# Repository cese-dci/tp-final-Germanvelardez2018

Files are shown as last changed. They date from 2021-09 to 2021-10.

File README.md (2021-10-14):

## Trabajo práctico final de la asignatura DCI ##
Este repositorio contiene el trabajo práctico final para la asignatura de Diseño de Circuitos Impresos de la carrera de posgrado de FIUBA.

* Autor: German Gabriel Velardez
* Título corto del trabajo:  Replica de modulo de comunicacion basado en el chip SIM7000G
* Descripción:  Modulo de comunicacion basado GSM/4G con GNSS incluido.

## Licencia de este trabajo ##
La licencia utilizada en este proyecto es : <b>CERN Open Hardware Licence Version 2</b>. 

## Estructura del TP FINAL ##

Se repositorio esta estructurado de la siguiente manera.

* doc: Toda la información sobre el circuito, principalmente de autoría o procesamiento propio. 
* info: Toda la iformación recolectada sobre el circuito, como por ejemplo:
  * Hojas de datos.
  * Info de productos comerciales.
  * Info en internet.
* pcb: Archivos de diseño esquemático y pcb.

## Replica de modulo de comunicacion basado en SIM7000
# Diseño final

 ### Dimensiones del nuevo modulo:
  <ul>
    <li>
     Largo: 80 mm
    </li>  
    <li>
    Ancho: 60 mm
    </li> 
  </lu> 

  ### Primera tentativa de posicionamiento de elementos
  
<p align="center">
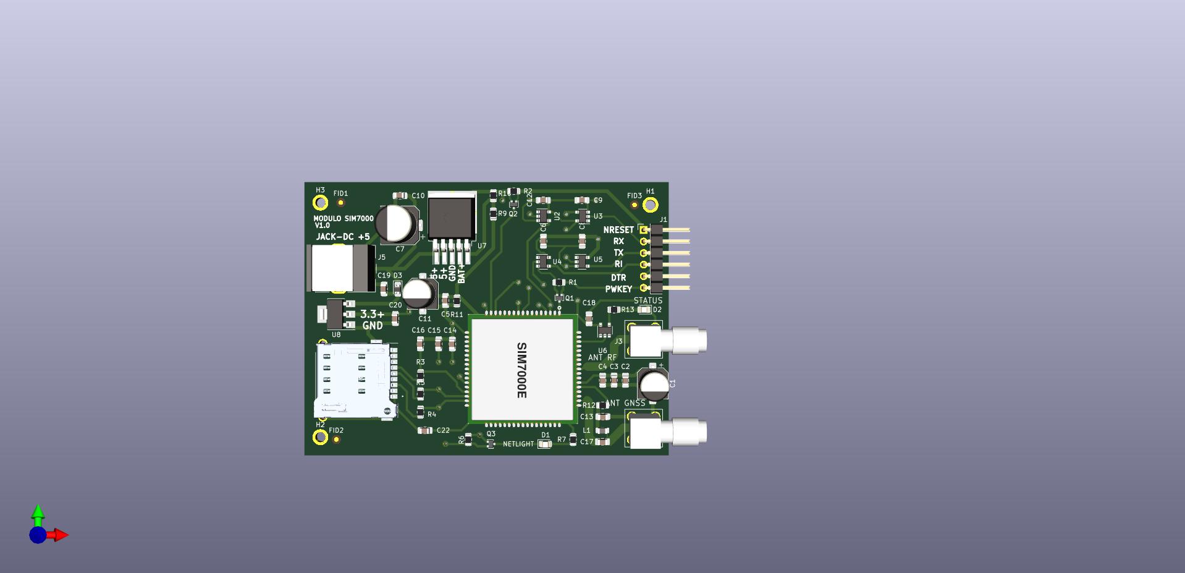
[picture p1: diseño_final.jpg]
  
</p>

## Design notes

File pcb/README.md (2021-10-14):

## Archivos Kicad ##
Este directorio contiene 2 carpetas:
<ul>
  <li>[lib] Librerias de componentes y modelos 3D</li>
  <li>[modulo_SIM7000G] Carpeta del proyecto KICAD</li>
  <ul>

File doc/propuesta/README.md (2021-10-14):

## Propuesta ##
En este directorio debe ir OBLIGATORIAMENTE la información que se presentó al momento de acordar la propuesta de TP con el docente. Es decir:
* Fotos e imágenes de las placas de ambos lados si es una réplica. 
* Fotos e imágenes de los prototipos cableados o pruebas si es un trabajo de tesis.
* Urls o info de origen. 
* Circuito esquemático de referencia (si es una réplica) o borrador si es un trabajo de tesis.
* Resumen de la función u objetivo del circuito si es un trabajo de tesis.
* Cualquier otra nota que se haya usado para definir el TP en el formulario de propuesta.

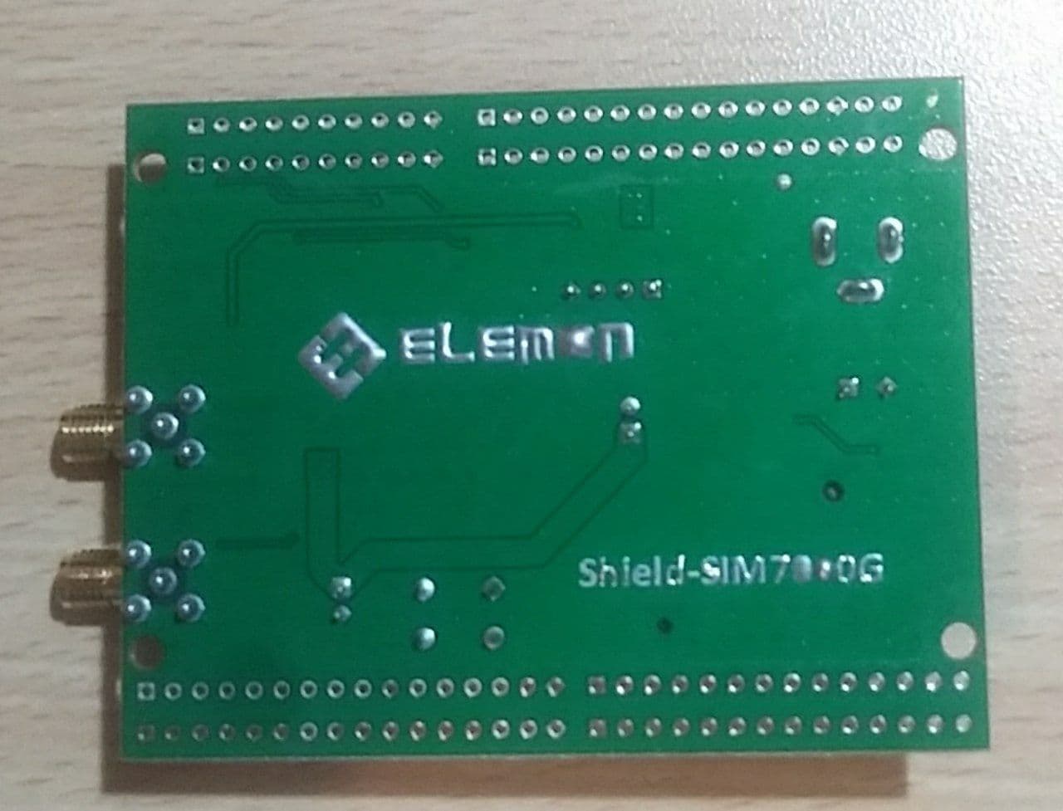
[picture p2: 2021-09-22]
doc/propuesta/fotos/vista_inferior.jpg

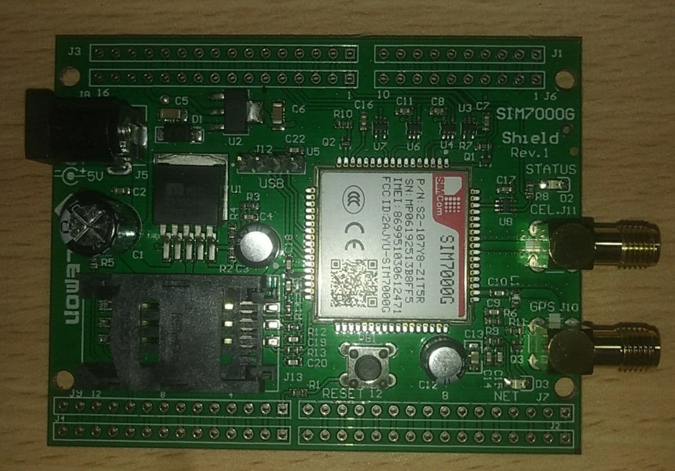
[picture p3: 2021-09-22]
doc/propuesta/fotos/vista_superior_flash.jpg

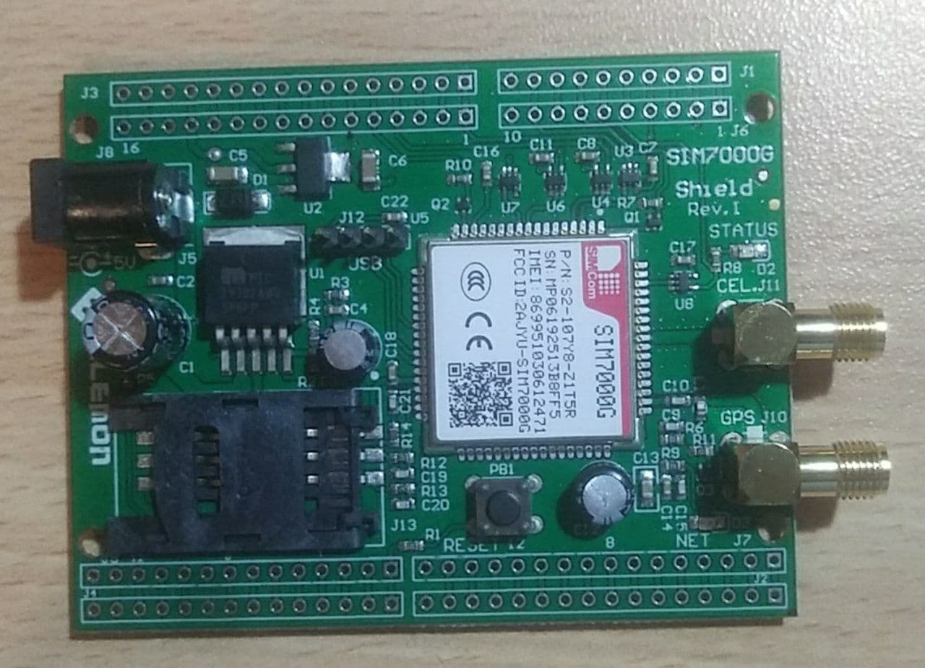
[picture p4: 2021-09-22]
doc/propuesta/fotos/vista_superior.jpg

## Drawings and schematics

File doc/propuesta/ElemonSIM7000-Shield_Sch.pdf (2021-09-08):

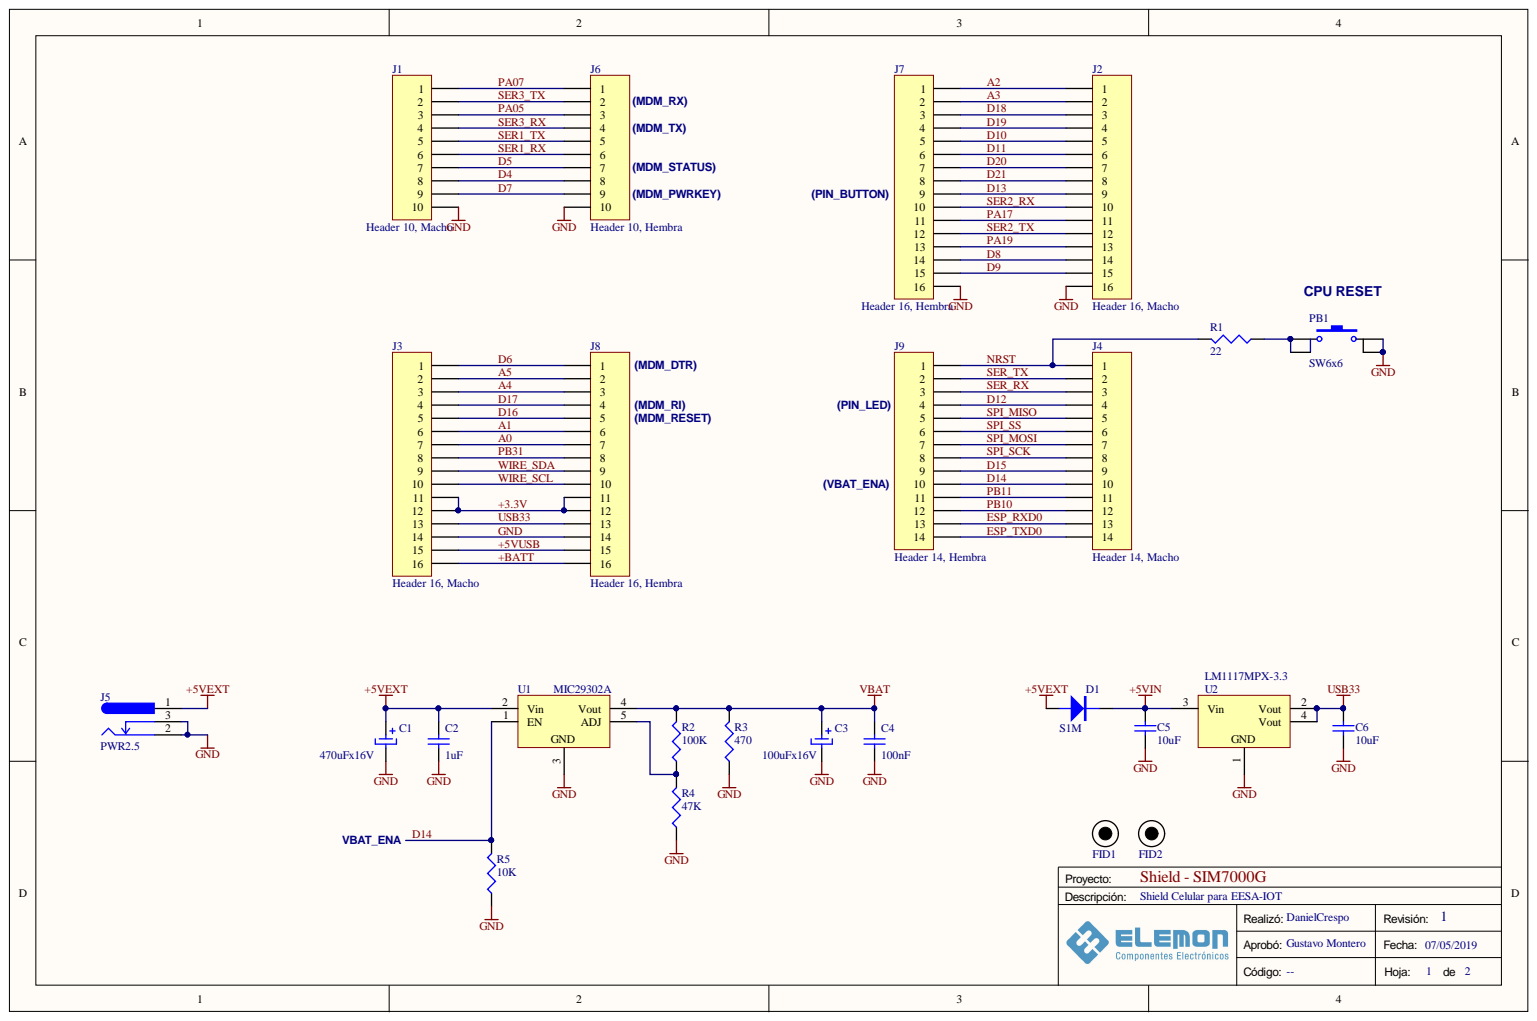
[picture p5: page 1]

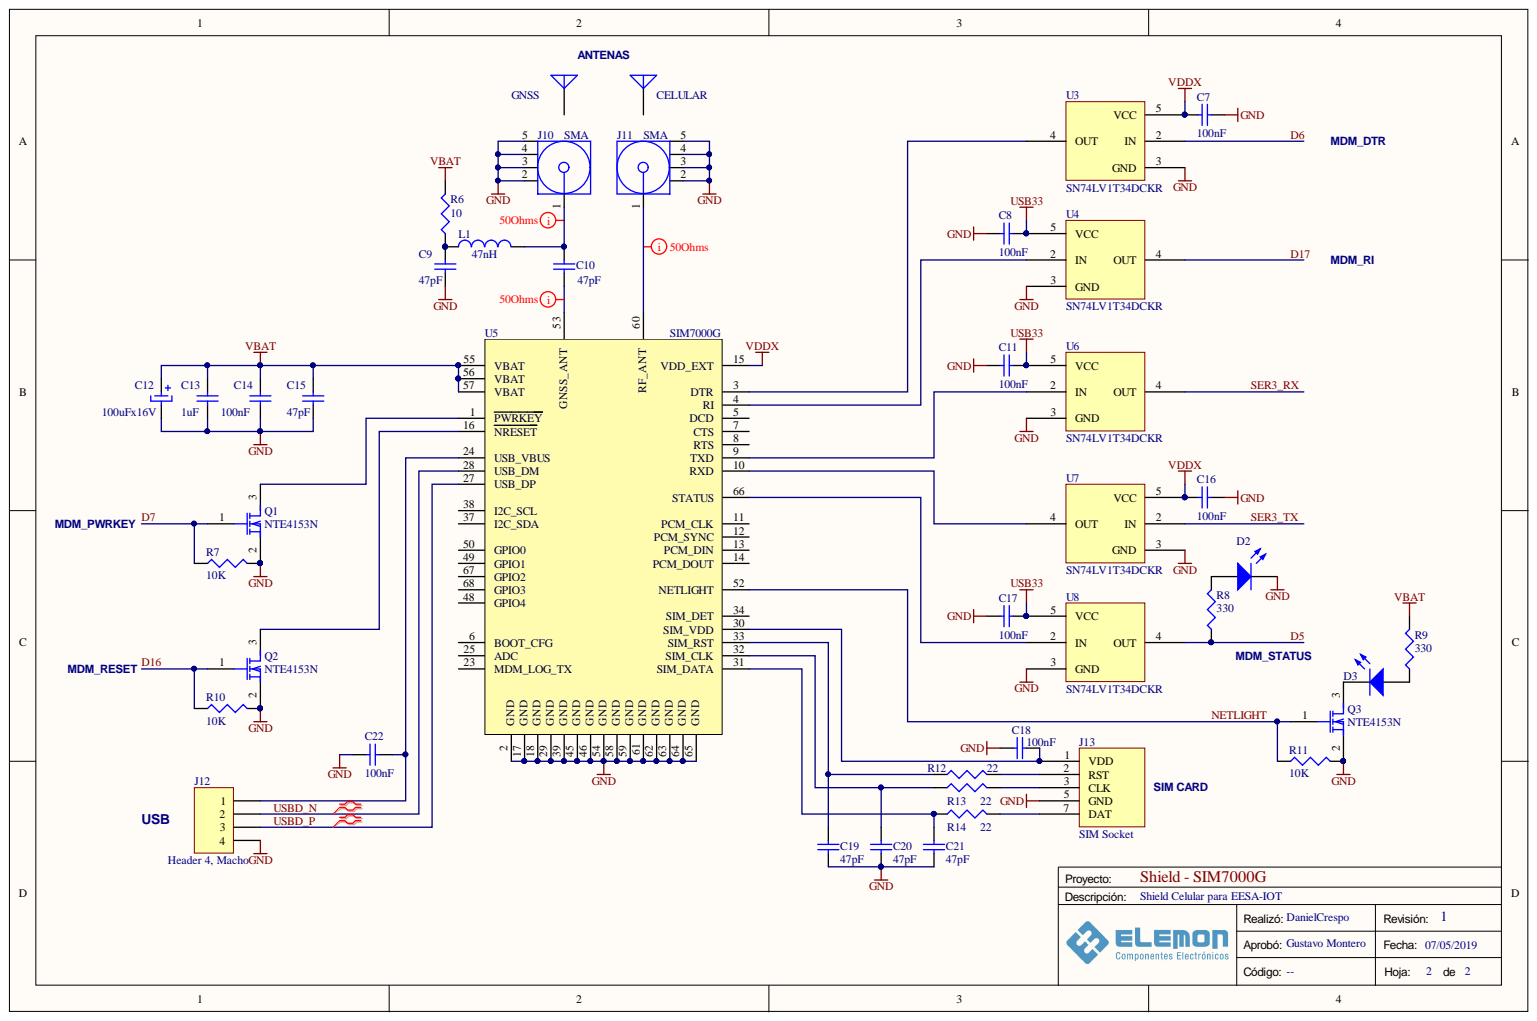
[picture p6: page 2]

2 4
2 8
2 7 | | 6 6

4 9 | 1 4
6 7 | 5 2 | 4 LV1T34DCKR

NTE4 153 N C 2 2 100 n F | | 3 3 | 100 n

2 5 | 3 2 | | FGND | 3

GND 65 GND 64 GND 63 GND 62 GND 61 GND 59 GND 58 GND 54 GND 46 GND 45 GND 39 GND 29 GND 18 GND 17 GND 2 MDM_LOG_TX

US BD_ N
US BD_ P

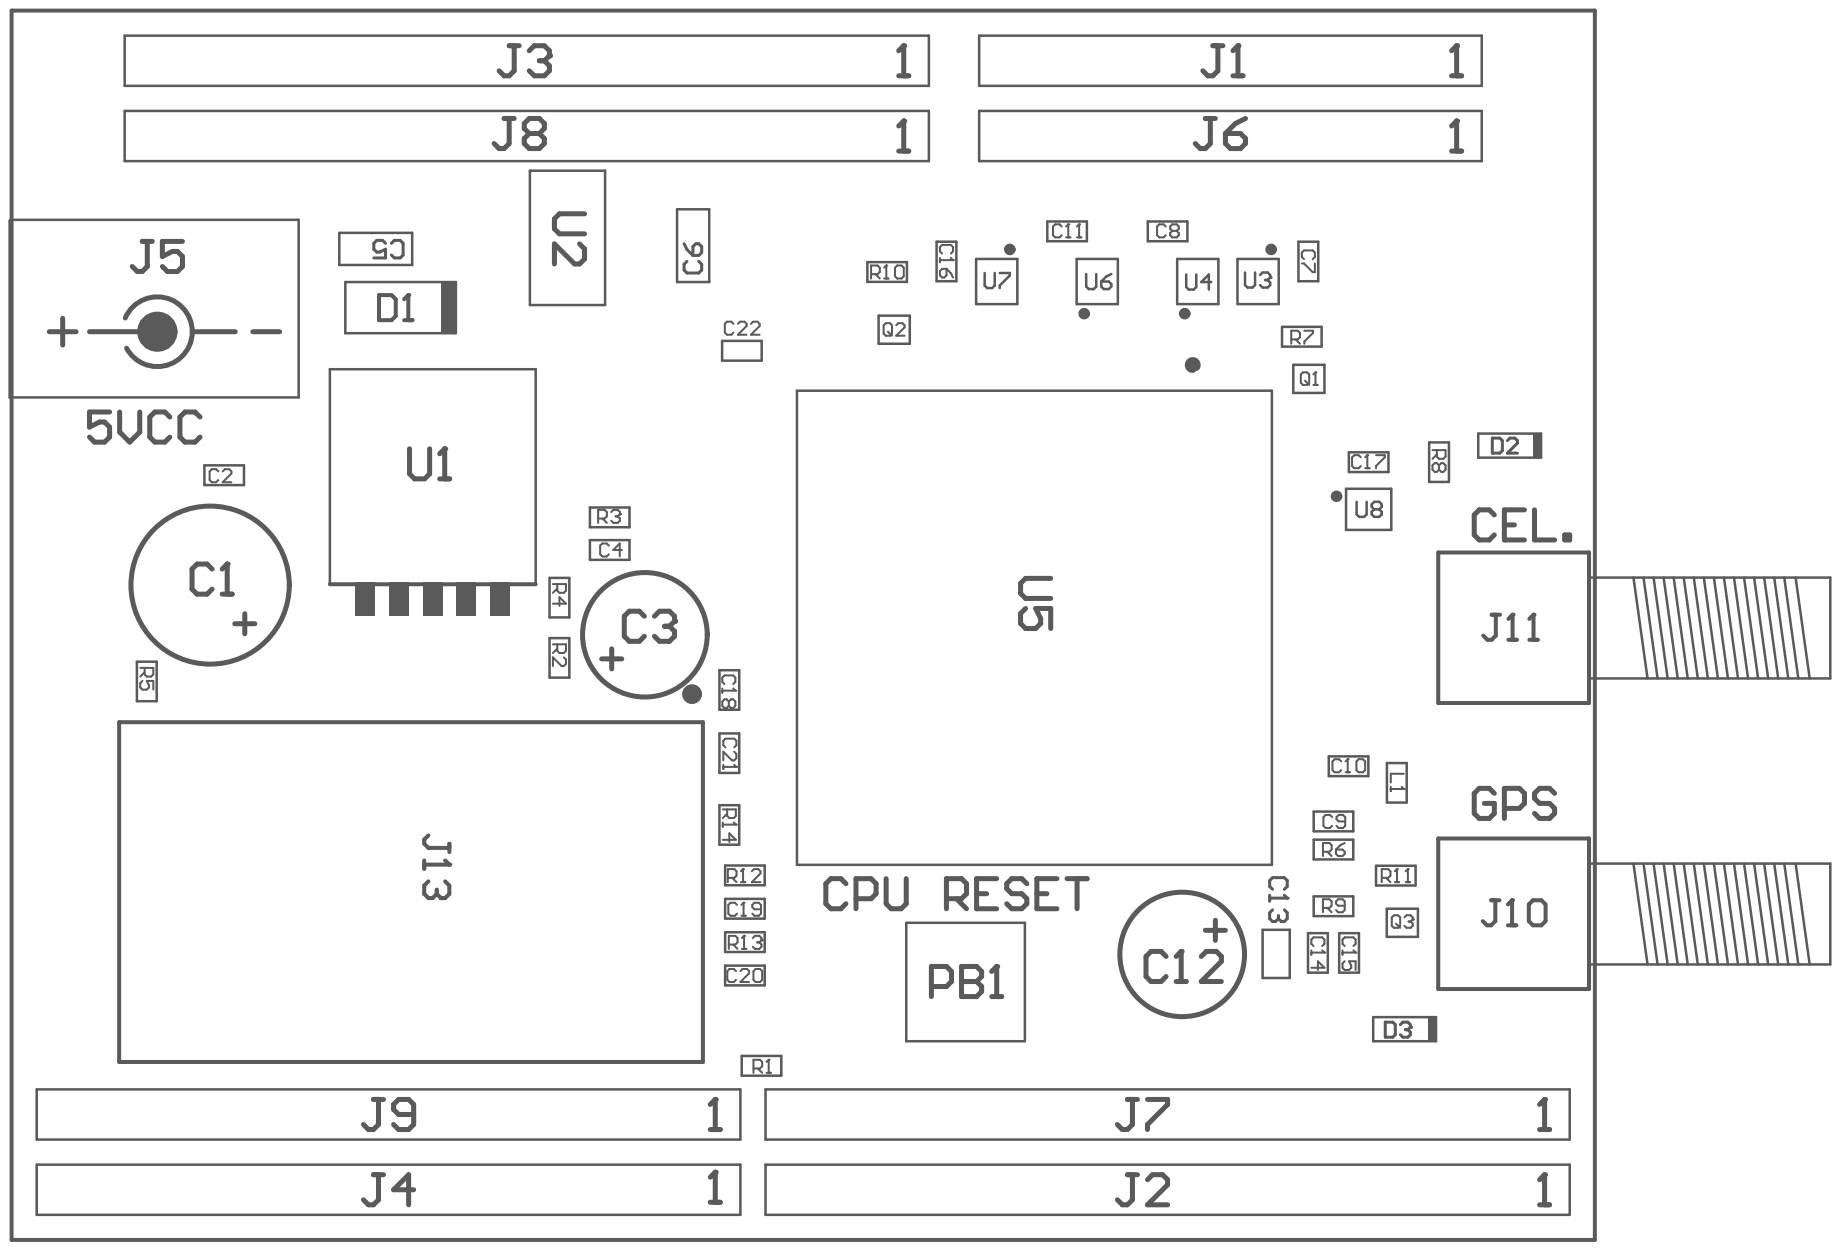
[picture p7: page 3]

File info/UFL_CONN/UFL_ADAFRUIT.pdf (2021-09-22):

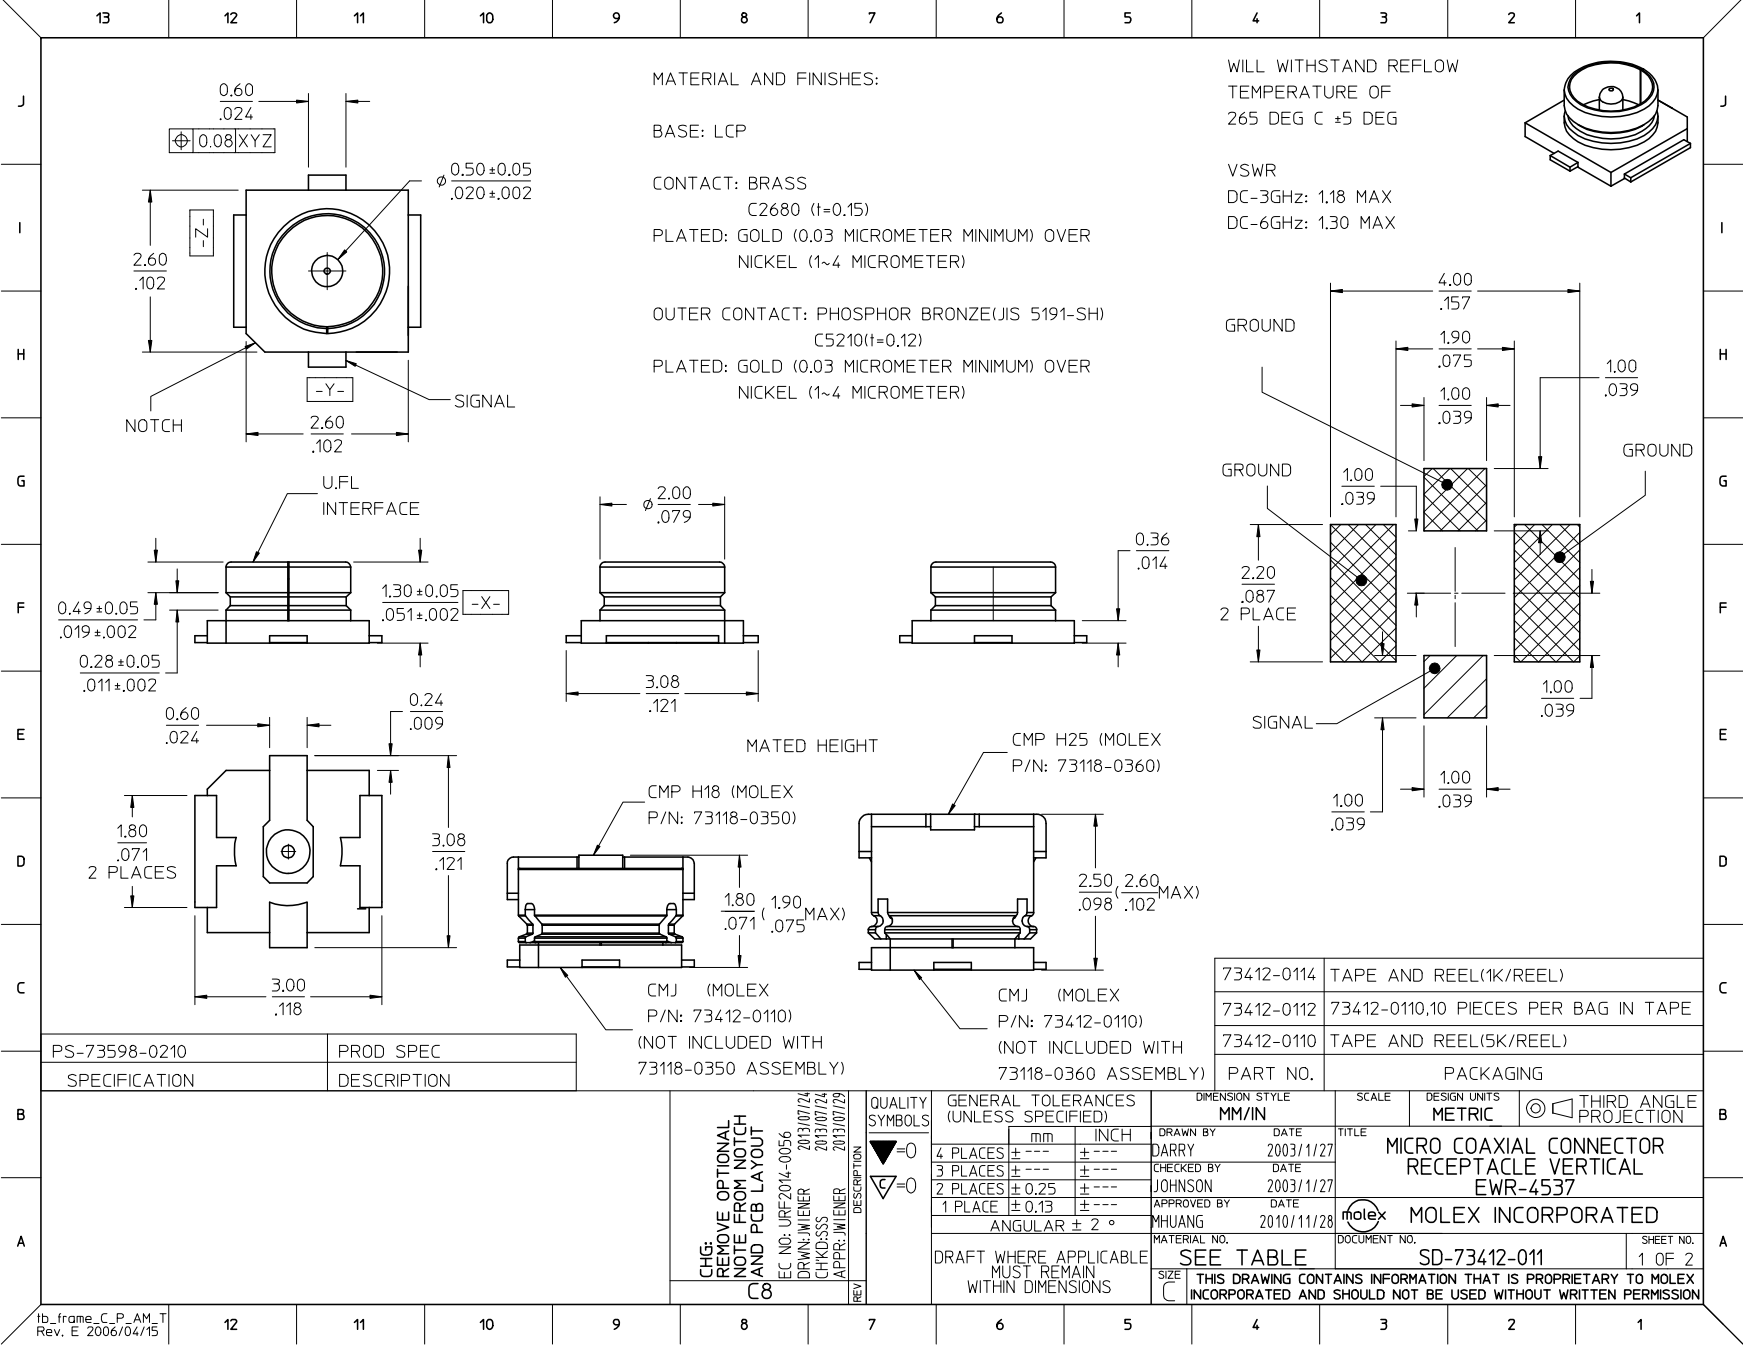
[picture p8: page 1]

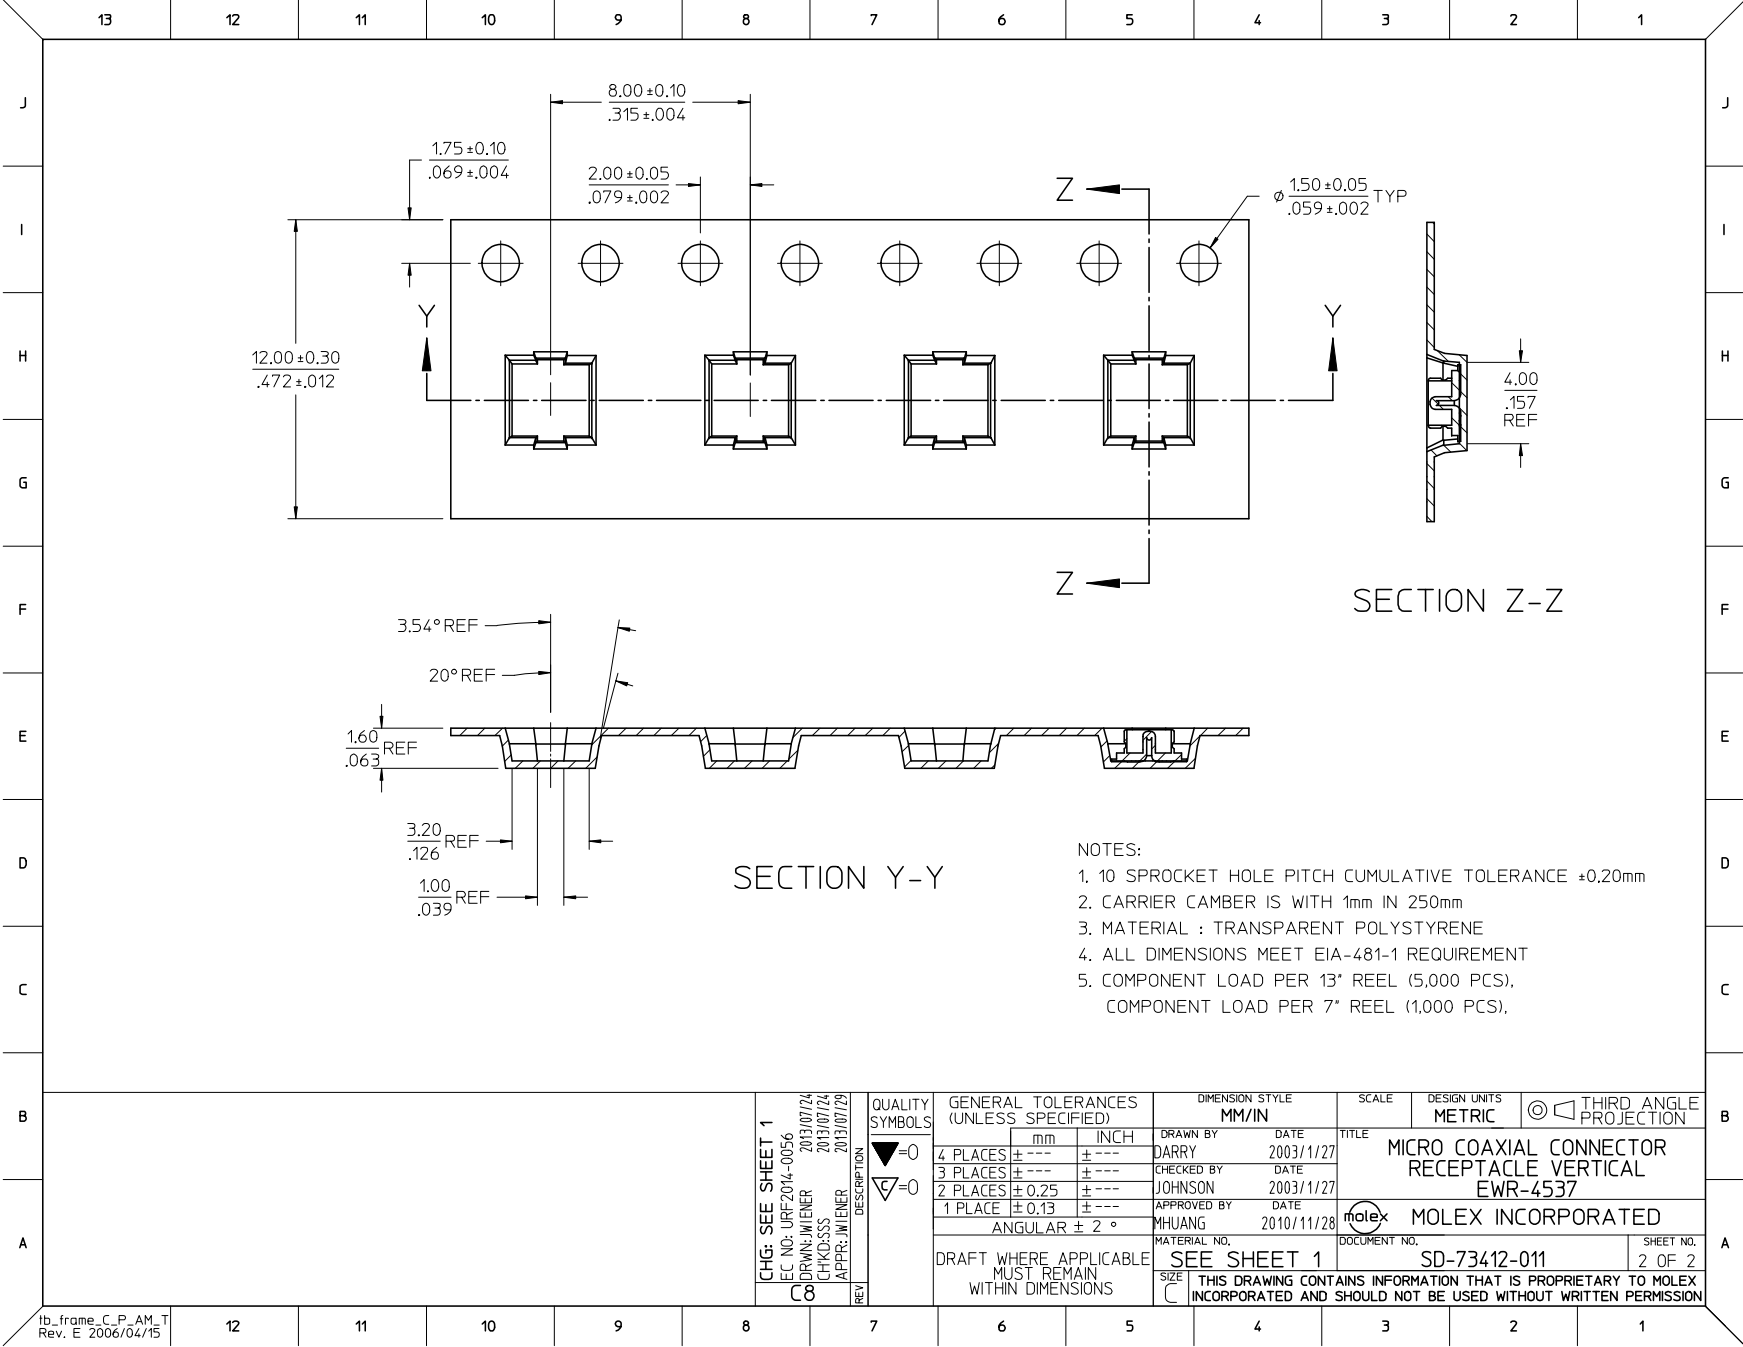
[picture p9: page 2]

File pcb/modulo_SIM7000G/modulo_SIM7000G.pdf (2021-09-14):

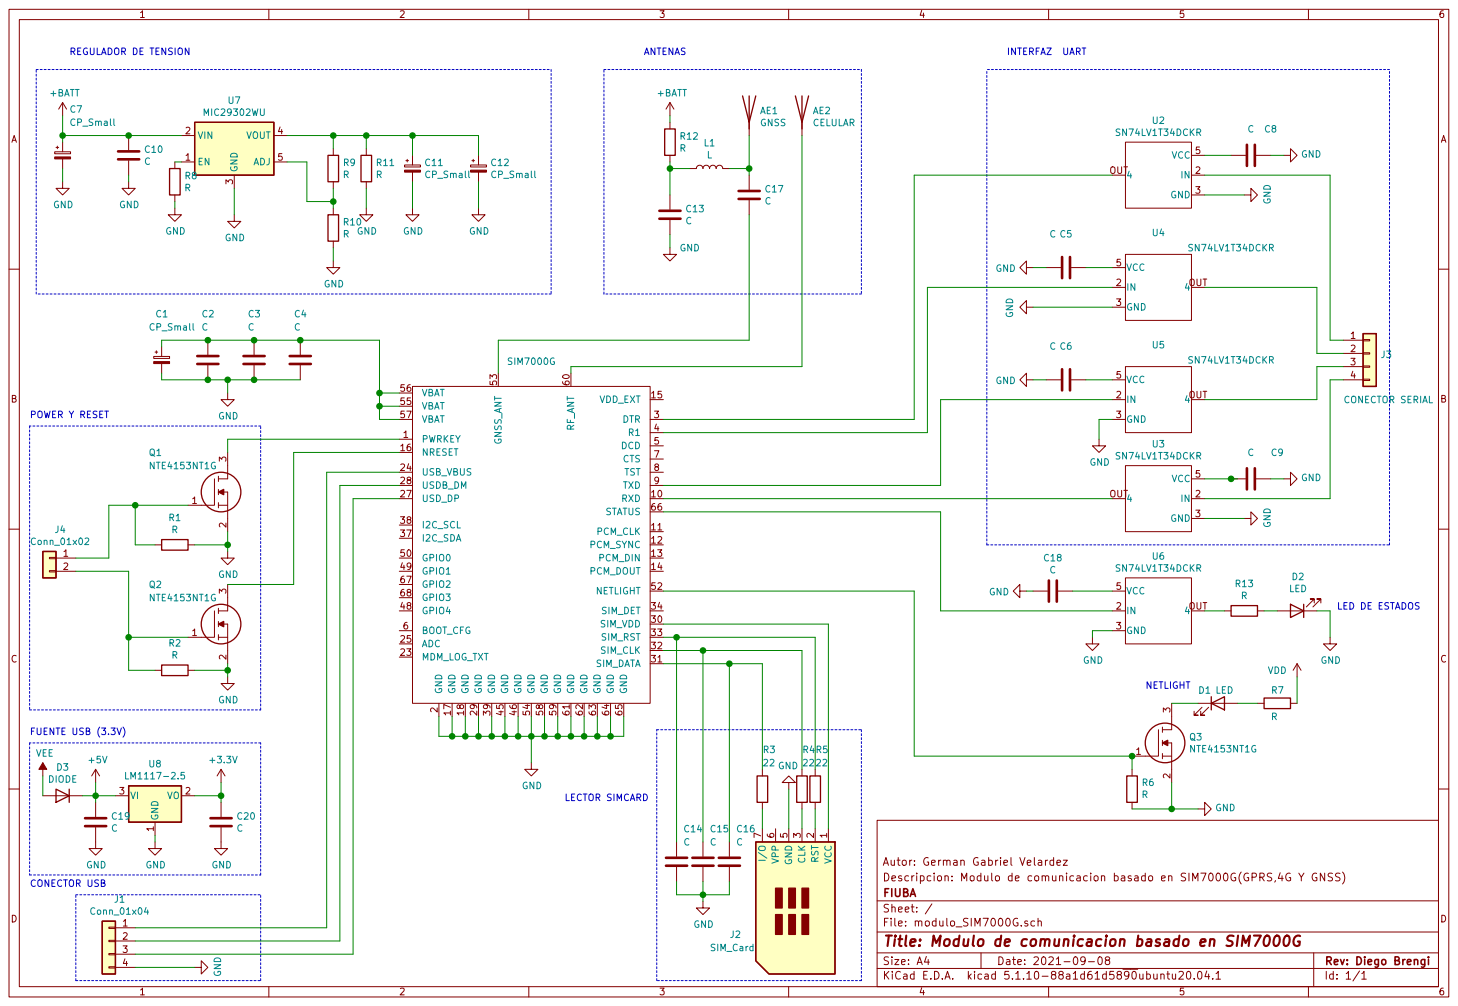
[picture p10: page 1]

Descripcion: Modulo de comunicacion basado en SIM7000G(GPRS,4G Y GNSS) Autor: German Gabriel Velardez

File: modulo_SIM7000G.sch Sheet: / FIUBA

Id: 1/1 Title: Modulo de comunicacion basado en SIM7000G

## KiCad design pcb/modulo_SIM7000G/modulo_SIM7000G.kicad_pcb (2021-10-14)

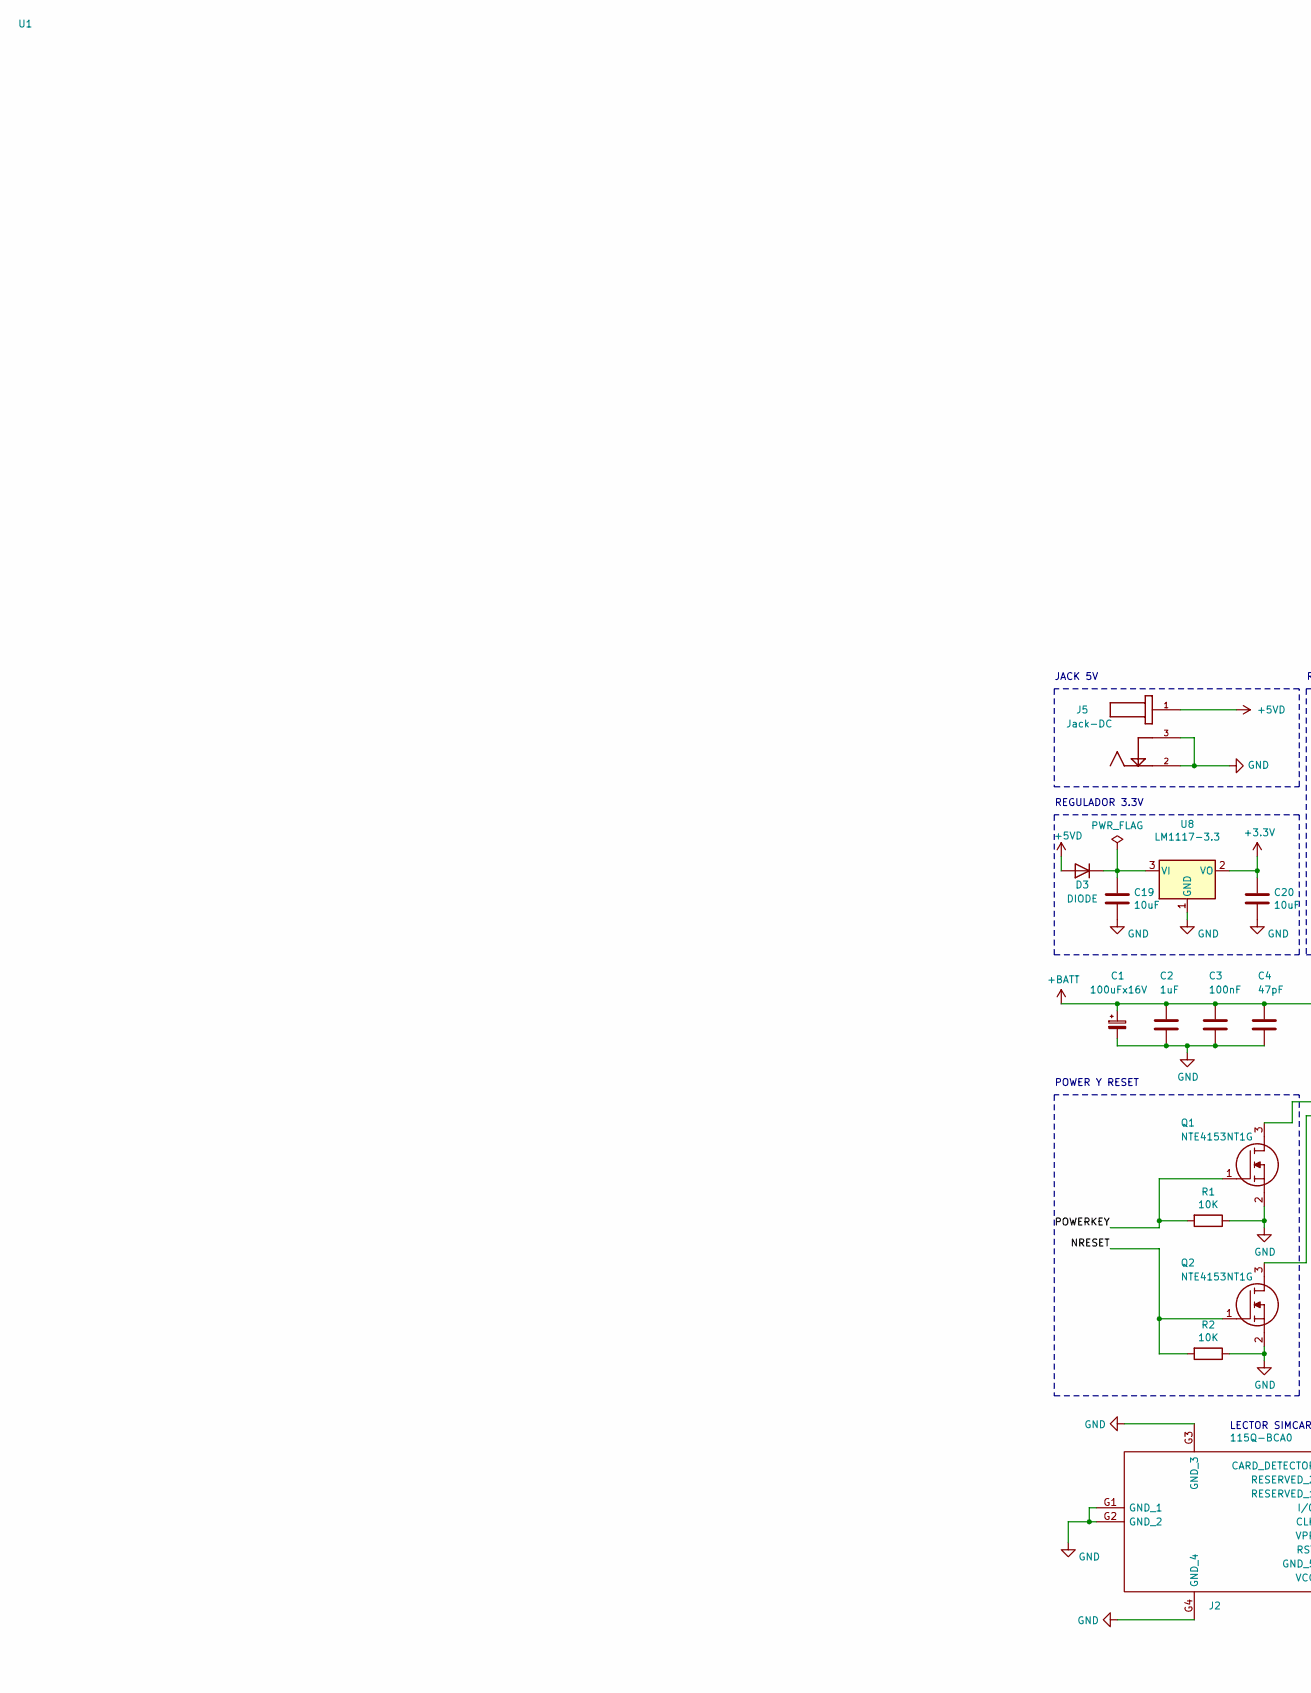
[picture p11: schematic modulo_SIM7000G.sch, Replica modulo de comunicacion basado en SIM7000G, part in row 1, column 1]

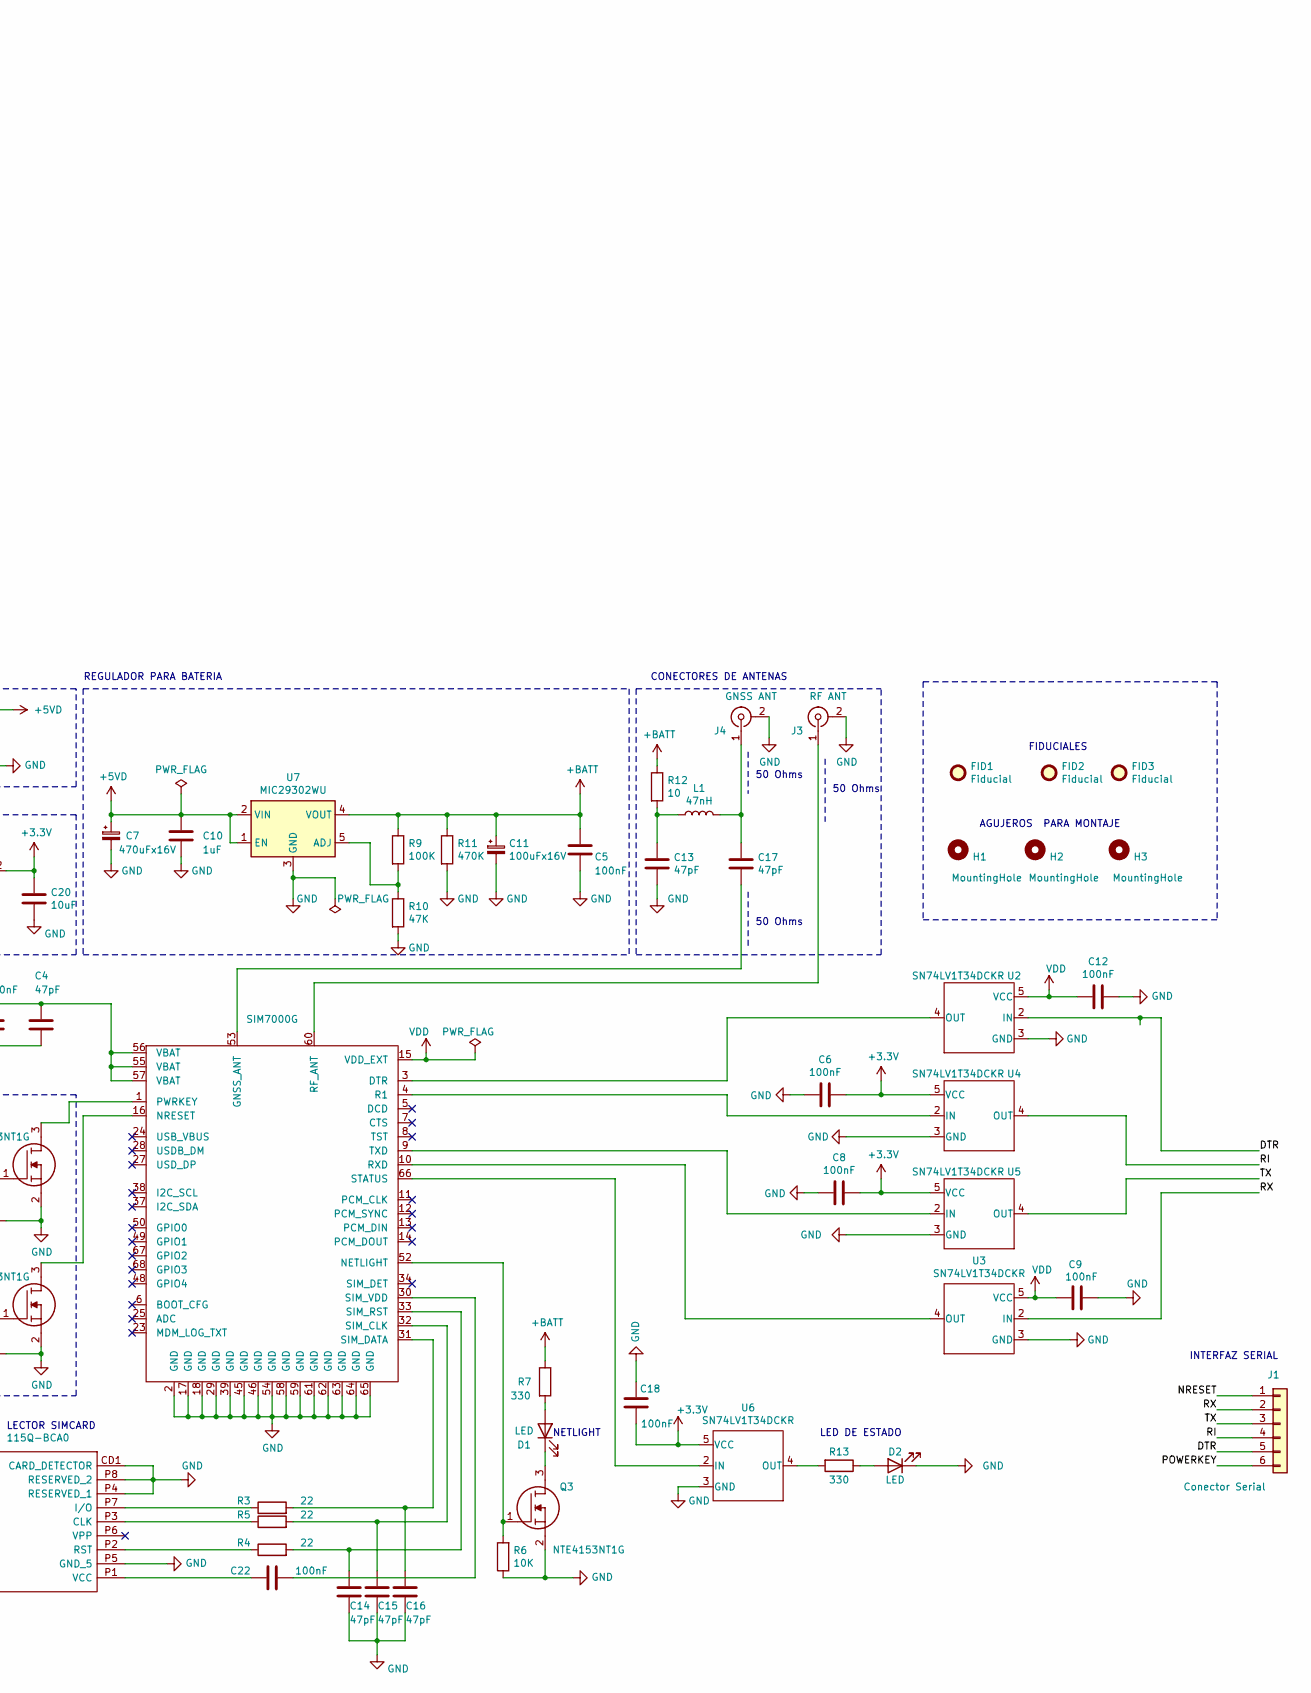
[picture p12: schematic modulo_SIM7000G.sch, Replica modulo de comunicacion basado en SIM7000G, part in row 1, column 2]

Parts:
C1, C11: 100uFx16V; CP_Elec_6.3x9.9
C2, C10: 1uF; C_0805_2012Metric_Pad1.18x1.45mm_HandSolder
C3, C5, C6, C8, C9, C12, C18, C22: 100nF; C_0805_2012Metric_Pad1.18x1.45mm_HandSolder
C4, C13, C14, C15, C16, C17: 47pF; C_0805_2012Metric_Pad1.18x1.45mm_HandSolder
C7: 470uFx16V; CP_Elec_8x10
C19, C20: 10uF; C_0805_2012Metric_Pad1.18x1.45mm_HandSolder
D1, D2: LED; LED_0805_2012Metric
D3: DIODE; D_0805_2012Metric_Pad1.15x1.40mm_HandSolder
FID1, FID2, FID3: Fiducial; Fiducial_1mm_Mask2mm
H1, H2, H3: MountingHole; MountingHole_2.2mm_M2_ISO7380_Pad_TopBottom
J1: Conector Serial; PinHeader_1x06_P2.54mm_Horizontal
J2: 115Q-BCA0; 115QBCA0; Manufacturer_Part_Number 115Q-BCA0
J3: RF ANT; SMA_Amphenol_132203-12_Horizontal
J4: GNSS ANT; SMA_Amphenol_132203-12_Horizontal
J5: Jack-DC; BarrelJack_CUI_PJ-063AH_Horizontal
L1: 47nH; L_0805_2012Metric
Q1, Q2, Q3: NTE4153NT1G; SOT-416; Manufacturer_Part_Number NTE4153NT1G; Mouser Part Number 863-NTE4153NT1G
R1, R2, R6: 10K; R_0805_2012Metric
R3, R4, R5: 22; R_0805_2012Metric
R7, R13: 330; R_0805_2012Metric
R9: 100K; R_0805_2012Metric
R10: 47K; R_0805_2012Metric
R11: 470K; R_0805_2012Metric
R12: 10; R_0805_2012Metric
U1: SIM7000G; SIM7000
U2, U3, U4, U5, U6: SN74LV1T34DCKR; SOT-23-5
U7: MIC29302WU; TO-263-5_TabPin3; Digikey 576-1125-2-NDTR
U8: LM1117-3.3; SOT-223

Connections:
+3V3: C6.2, C8.2, C18.1, C20.1, U4.5 (VCC), U5.5 (VCC), U6.5 (VCC), U8.2 (VO)
+5VD: C7.1, C10.1, D3.1 (A), J5.1, U7.1 (EN), U7.2 (VIN)
+BATT: C1.1, C2.1, C3.1, C4.1, C5.1, C11.1, R7.1, R9.1, R11.1, R12.1, U1.55 (VBAT), U1.56 (VBAT), U1.57 (VBAT), U7.4 (VOUT)
/DTR: J1.5, U2.2 (IN)
/NRESET: J1.1, Q2.1, R2.2
/POWERKEY: J1.6, Q1.1, R1.2
/RI: J1.4, U4.4 (OUT)
/RX: J1.2, U3.2 (IN)
/TX: J1.3, U5.4 (OUT)
GND: C1.2, C2.2, C3.2, C4.2, C5.2, C6.1, C7.2, C8.1, C9.2, C10.2, C11.2, C12.2, C13.2, C14.2, C15.2, C16.2, C18.2, C19.2, C20.2, D2.1 (K), J2.CD1 (CARD_DETECTOR), J2.G1 (GND_1), J2.G2 (GND_2), J2.G3 (GND_3), J2.G4 (GND_4), J2.P4 (RESERVED_1), J2.P5 (GND_5), J2.P8 (RESERVED_2), J3.2 (Ext), J4.2 (Ext), J5.2, J5.3, Q1.2, Q2.2, Q3.2, R1.1, R2.1, R6.1, R10.2, R11.2, U1.2 (GND), U1.17 (GND), U1.18 (GND), U1.29 (GND), U1.39 (GND), U1.45 (GND), U1.46 (GND), U1.54 (GND), U1.58 (GND), U1.59 (GND), U1.61 (GND), U1.62 (GND), U1.63 (GND), U1.64 (GND), U1.65 (GND), U2.3 (GND), U3.3 (GND), U4.3 (GND), U5.3 (GND), U6.3 (GND), U7.3 (GND), U8.1 (GND)
unnamed: C13.1, L1.1, R12.2
unnamed: C14.1, R4.2, U1.33 (SIM_RST)
unnamed: C15.1, R5.2, U1.32 (SIM_CLK)
unnamed: C16.1, R3.2, U1.31 (SIM_DATA)
unnamed: C17.1, J4.1 (In), L1.2
unnamed: C17.2, U1.53 (GNSS_ANT)
unnamed: C19.1, D3.2 (K), U8.3 (VI)
unnamed: C22.1, J2.P1 (VCC)
unnamed: C22.2, U1.30 (SIM_VDD)
unnamed: D1.1 (K), Q3.3
unnamed: D1.2 (A), R7.2
unnamed: D2.2 (A), R13.1
unnamed: J2.P2 (RST), R4.1
unnamed: J2.P3 (CLK), R5.1
unnamed: J2.P7 (I/O), R3.1
unnamed: J3.1 (In), U1.60 (RF_ANT)
unnamed: Q1.3, U1.1 (PWRKEY)
unnamed: Q2.3, U1.16 (NRESET)
unnamed: Q3.1, R6.2, U1.52 (NETLIGHT)
unnamed: R9.2, R10.1, U7.5 (ADJ)
unnamed: R13.2, U6.4 (OUT)
unnamed: U1.3 (DTR), U2.4 (OUT)
unnamed: U1.4 (R1), U4.2 (IN)
unnamed: U1.9 (TXD), U5.2 (IN)
unnamed: U1.10 (RXD), U3.4 (OUT)
unnamed: U1.66 (STATUS), U6.2 (IN)
VDD: C9.1, C12.1, U1.15 (VDD_EXT), U2.5 (VCC), U3.5 (VCC)

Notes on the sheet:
REGULADOR 3.3V
POWER Y RESET
FIDUCIALES
AGUJEROS PARA MONTAJE
JACK 5V
REGULADOR PARA BATERIA
LECTOR SIMCARD
NETLIGHT
LED DE ESTADO
CONECTORES DE ANTENAS
INTERFAZ SERIAL
50 Ohms

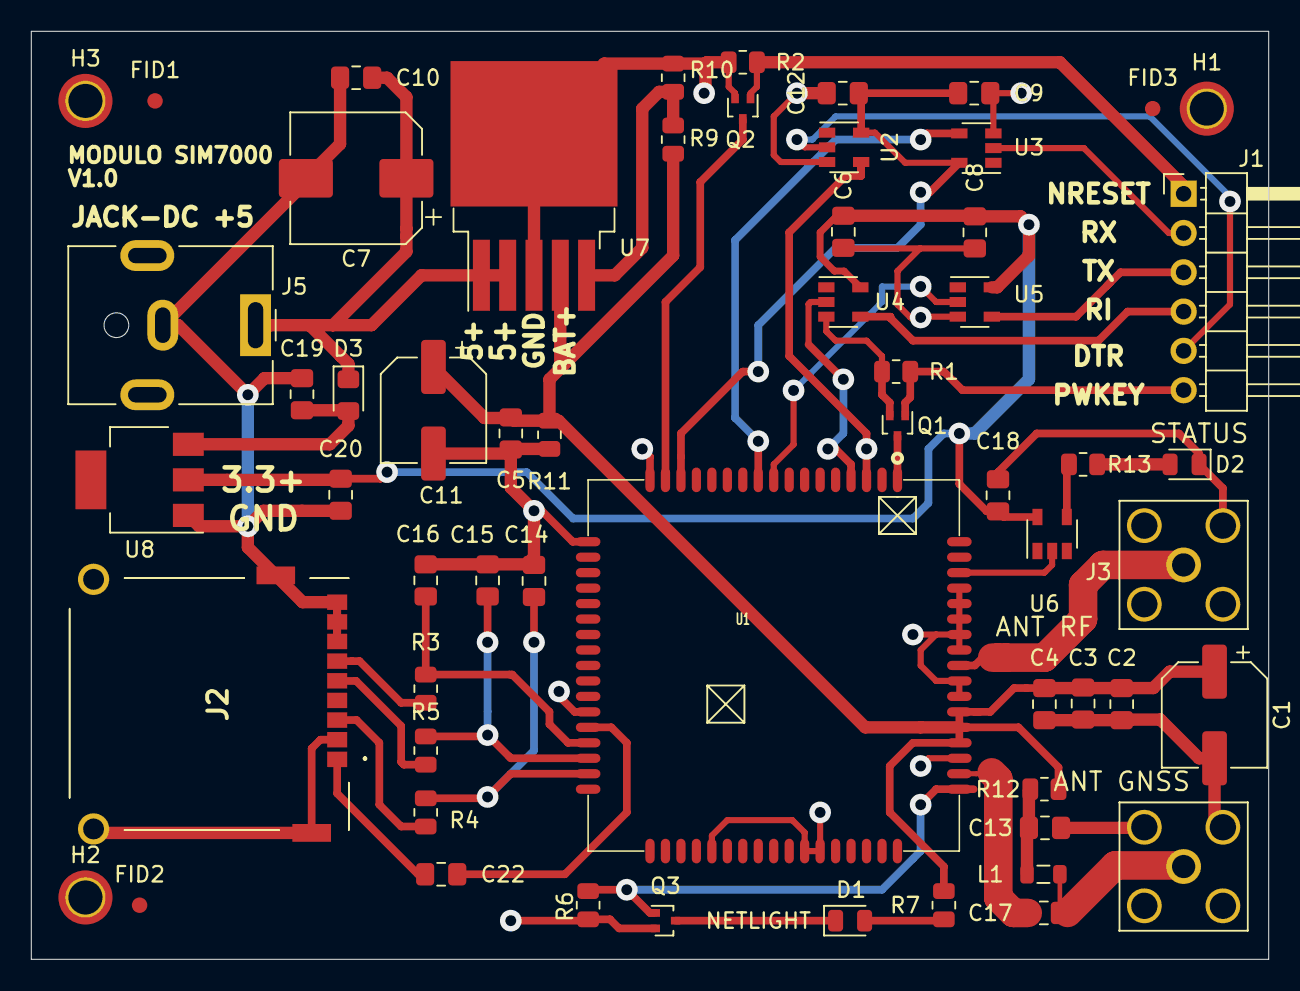
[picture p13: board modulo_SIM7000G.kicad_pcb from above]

Board: 2 copper layers, 80.0 x 60.0 mm, 59 parts (0 on the bottom side), 37 nets.

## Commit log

2021-09-08 Se Completado datos en el readme
2021-09-08 Avances en el esquematico del circuito
    [modulo_SIM7000G.kicad_pcb, modulo_SIM7000G.sch]
2021-09-14 avances en el esquematico(casi terminado) consultar detalles sobre como poner referencias a USB33, VBAT, VEXT, ect
    [modulo_SIM7000G.sch]
2021-09-14 mejora en el esquematico
    [modulo_SIM7000G.sch]
2021-09-14 avance en el esquematico, se posiciono todos los componentes, solo falta agregar VBAT, V5EXT y otras referencia de tension donde corresponda
    [modulo_SIM7000G.sch]
2021-09-16 se agregaron valores a componentes
    [modulo_SIM7000G.sch]
2021-09-22 Modificaciones en el esquematico, se agrego un conector lector de sim modelo 115Q-BCA0
    [115Q-BCA0.stl, 115Q-BCA0.stp, DCJ200-10-A-XX-X_REVA.step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]
2021-09-22 se agrego imagen de posicionmiento tentativo
    [modulo_SIM7000G.kicad_pcb]
2021-09-22 Acomodando archivos y carpetas del repo
    [115Q-BCA0.stl, 115Q-BCA0.stp, DCJ200-10-A-XX-X_REVA.step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]
2021-09-22 Se agrego connectores de antenas
    [I-PEX MHF_7 Recepticle.STEP, SIM7000.step, comm_ufl.step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]
2021-09-22 se mejoror imagen de posicionamiento tentativo
2021-09-22 modificaciones en el readme de propuesta
2021-09-22 Se generaron los archivos de asignacion de huellas y figuras 3d
    [modulo_SIM7000G.kicad_pcb, modulo_SIM7000G.sch, u.Fl Antenna Connector - 523-A-1JB.SLDPRT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]
2021-09-24 correciones en el esquematico, se agrego agujeros de montaje
    [modulo_SIM7000G.kicad_pcb, modulo_SIM7000G.sch]
2021-09-29 antes de empezar el diseño de las pistas
    [modulo_SIM7000G.kicad_pcb, modulo_SIM7000G.sch]
2021-10-07 se termino de diseñar las pistas. Falta plano de alimentacion y detalles
    [SIM7000.step, modulo_SIM7000G.kicad_pcb, modulo_SIM7000G.sch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]
2021-10-07 pcb terminado.
    [modulo_SIM7000G.sch, v1.kicad_pcb]
2021-10-08 modificaciones en reglas de diseño del proyecto
    [modulo_SIM7000G.kicad_pcb]
2021-10-12 antes de realizar modificaciones rf
    [modulo_SIM7000G.kicad_pcb, posicionamientoA_terminado.kicad_pcb]
2021-10-13 termine, falta los modelos 3d de los conectores.
    [modulo_SIM7000G.kicad_pcb, modulo_SIM7000G.sch]
2021-10-13 se redujo el tamaño de el pcb de 100x60 a 80x 60
    [modulo_SIM7000G.kicad_pcb]
2021-10-14 Se agrego los conectores de antenas. Faltasolucionar tema rutas relativas
    [modulo_SIM7000G.kicad_pcb]
2021-10-14 conectando nodos
    [modulo_SIM7000G.kicad_pcb]
2021-10-14 todo listo, menos el tema de las rutas relativas
    [modulo_SIM7000G.kicad_pcb]

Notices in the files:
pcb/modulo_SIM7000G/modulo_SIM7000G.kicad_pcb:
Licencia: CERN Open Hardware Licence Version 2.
